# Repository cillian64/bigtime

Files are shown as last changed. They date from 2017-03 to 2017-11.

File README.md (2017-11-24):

# bigtime
A rather large wall clock using big 7-segment displays, powered by 802.3af
power-over-ethernet, and synchronised using NTP over wired ethernet.
Configuration is done using an interactive USB shell and stored in flash.

One of these clocks is deployed in each of Lecture Theatres 1 and 2 at the
[Department of Computer Science and Technology](https://www.cst.cam.ac.uk/)
(formerly known as the [Computer Lab](https://www.cl.cam.ac.uk/)), [University
of Cambridge](https://www.cam.ac.uk/), UK.

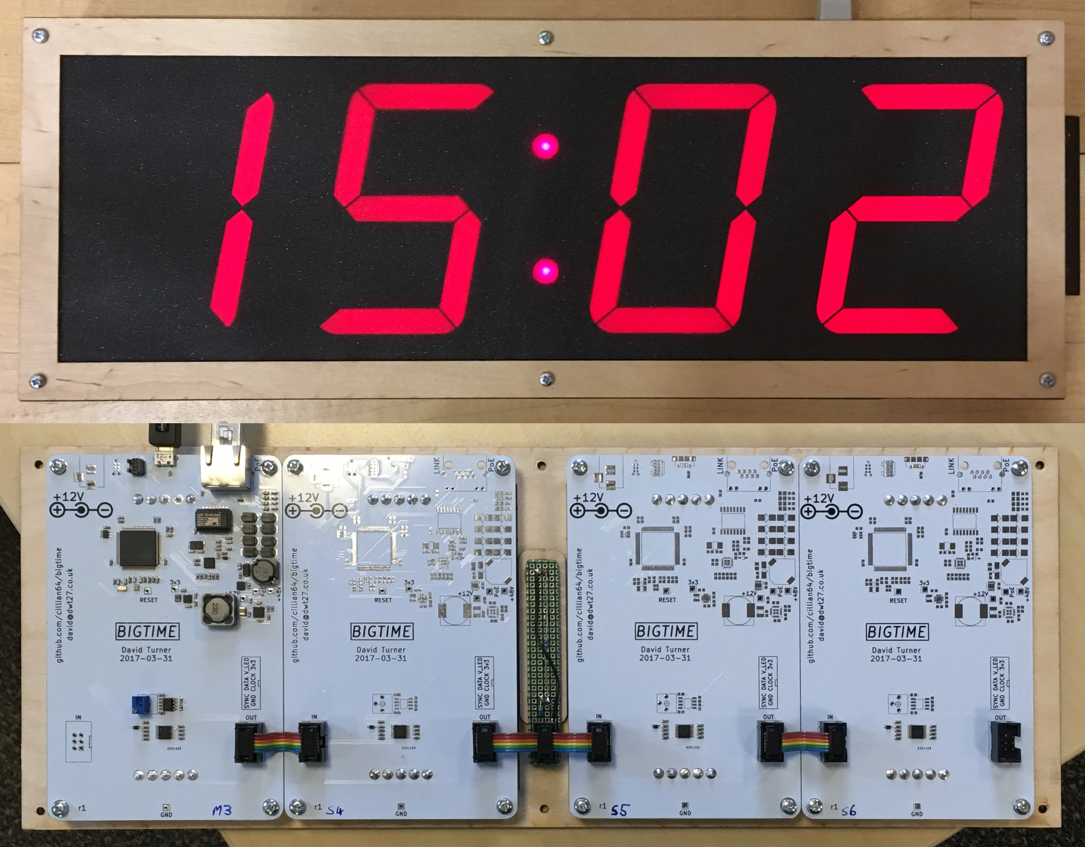
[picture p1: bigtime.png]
Photos of the front and back of the clock


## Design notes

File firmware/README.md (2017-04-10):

# Setting Up ChibiOS

```
git submodule update --init
cd ChibiOS/ext
7za x lwip-1.4.1_patched.7z
cd ..
patch -p0 < ../lwip_ip_addr.patch
git apply ../lwip_dhcp.patch
cd ..
```

# Logic
## Architecture
### Shared data
The STM32F4 RTC peripheral's date-time will hold the current time in UTC:
* Year (BCD)
* Month (BCD)
* Day of month (BCD)
* Day of week (BCD)
* Hour (BCD)
* Minute (BCD)
* Second (BCD)
* Sub-second

Other state is held in RAM:
* Time of last sync             (datetime)
* NTP server 1 status           (int)
* NTP server 1 query time       (datetime)
* NTP server 2 status           (int)
* NTP server 2 query time       (datetime)
* NTP server 3 status           (int)
* NTP server 3 query time       (datetime)

Non-volatile storage will be used to hold configuration:
* Network
    * DHCP enable               (bool)
    * IP address                (uint32_t IP address)
    * Network mask              (uint32_t IP address)
    * Gateway IP address        (uint32_t IP address)
    * DNS server 1              (uint32_t IP address)
    * DNS server 2              (uint32_t IP address)
* NTP
    * NTP server 1              (string)
    * NTP server 2              (string)
    * NTP server 3              (string)
    * Synchronisation interval  (uint16_t in minutes)
* Time and Display
    * Flashing second indicator (bool)
    * Display sync status       (bool)
    * Has seconds display       (bool)
    * Automatic BST adjustment  (bool)

### Threads
The display thread will retrieve the time from the RTC, the sync status from
the state structure, and the display settings from the configuration structure.
It will then drive the LED shift registers.  It will display the current time,
the seconds indicator if enabled, and the sync indicator if enabled and
currently unsynchronised.

The NTP thread will handle time synchronisation.  It will run through each NTP
server in the list and attempt to retrieve the time.  Upon a receive timeout it
will retry the same server several times.  Upon a network failure or KoD
response, it will proceed to the next server in the list.  If the final server
on the list fails, the NTP thread will return to the first server.  If all
servers are being avoided due to KoD, the NTP thread will wait until a server
becomes available again.  After a successful synchronisation it will update the
RTC peripheral and store the time of synchronisation.  It then waits until the
synchronisation interval has passed.

## Time anomalies
### Timezones
Only London time (GMT/BST) is supported currently.

### Daylight Savings adjustments
DST is applied using the rules for British Summer Time.  BST begins at 0100 UTC
on the last Sunday in March and ends at 0100 UTC on the last Sunday in October.
If the current date-time falls between these moments then the DST feature of
the RTC peripheral is enabled.  This automatically adds an hour to the time,
before timezone adjustment.

### Leap years
Knowing the calendar date, the RTC peripheral automatically compensates for
leap years.

### Leap seconds
If we pay no attention to leap seconds, we will be incorrect by 1 second
between a leap second and our next NTP synchronisation.  For a clock with a
precision of minutes, this seems acceptable.

NTP does provide advance warning of a leap second which we could use manually
adjust the RTC time between the leap second occurring and our next successful
synchronisation.  I strongly suspect the RTC peripheral will not handle a
seconds value of 60, so if we want to display the correct time, with a
precision of seconds, during the leap second, we will probably need to apply
the offset after reading the time from the RTC (i.e. at the same time as
timezone adjustment) and ensure our time-handling and display procedures can
handle a 61 second minute.

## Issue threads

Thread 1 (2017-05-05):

WAD connection needs diode

cillian64, 2017-05-05:
The barrel jack should connect directly to WAD on the MAX5969, then through a diode to the 12V bus.  This would prevent the 12V power from the MAX17503 triggering the WAD cutoff, causing the 48V and downstream buses to oscillate.

Workaround: The WAD track was cut

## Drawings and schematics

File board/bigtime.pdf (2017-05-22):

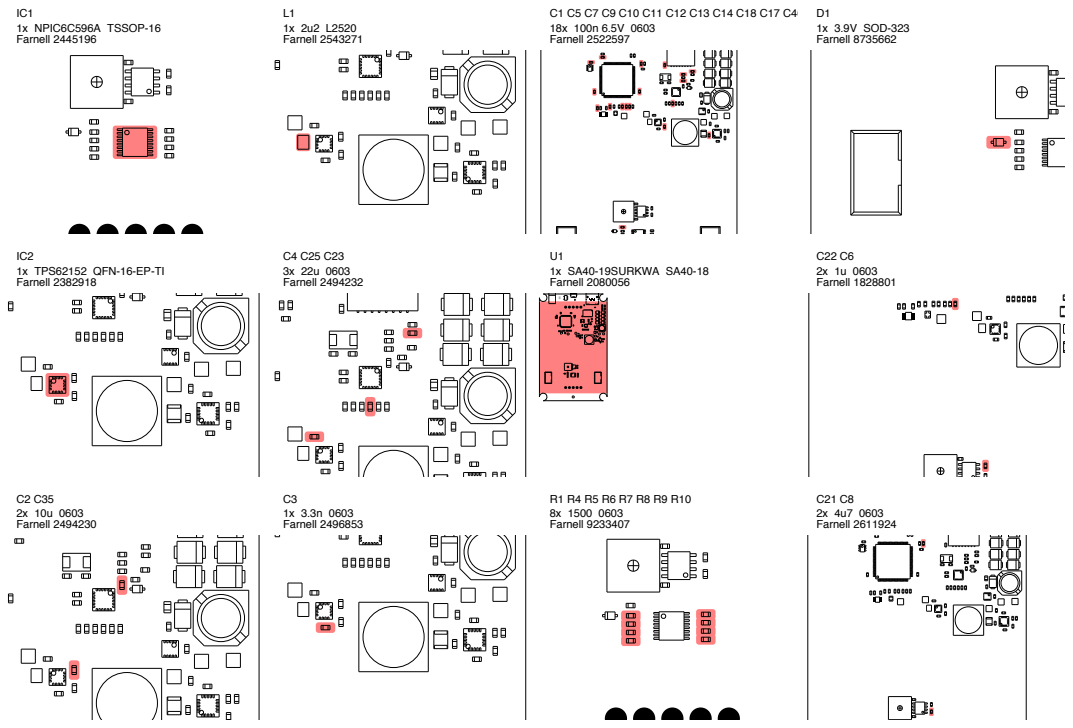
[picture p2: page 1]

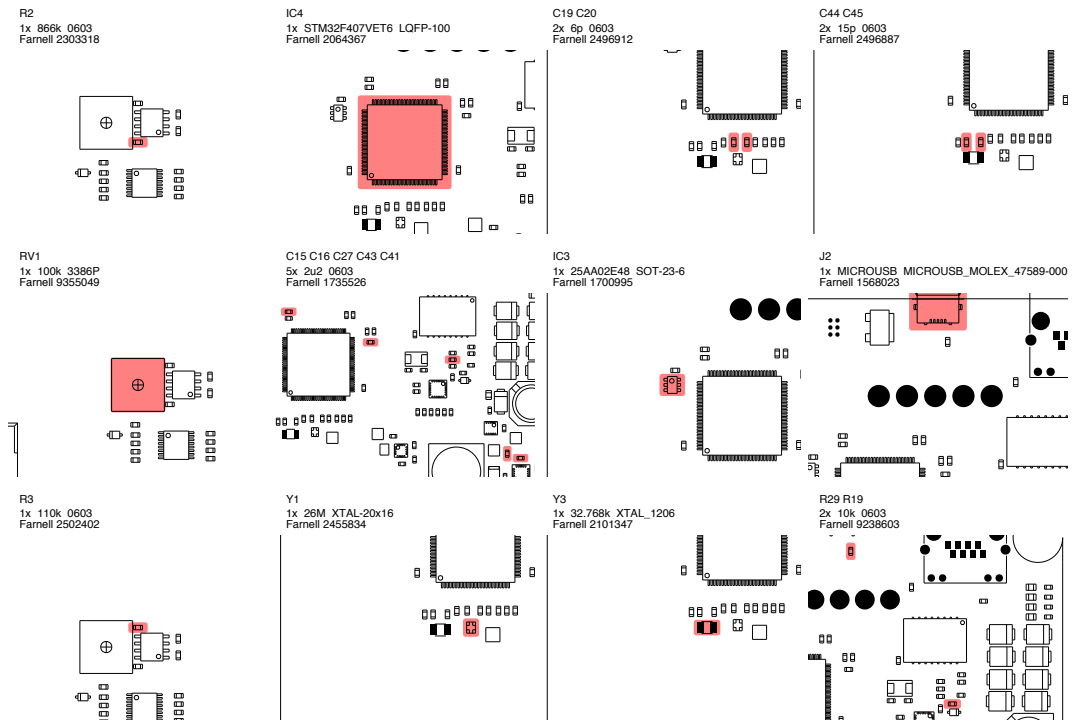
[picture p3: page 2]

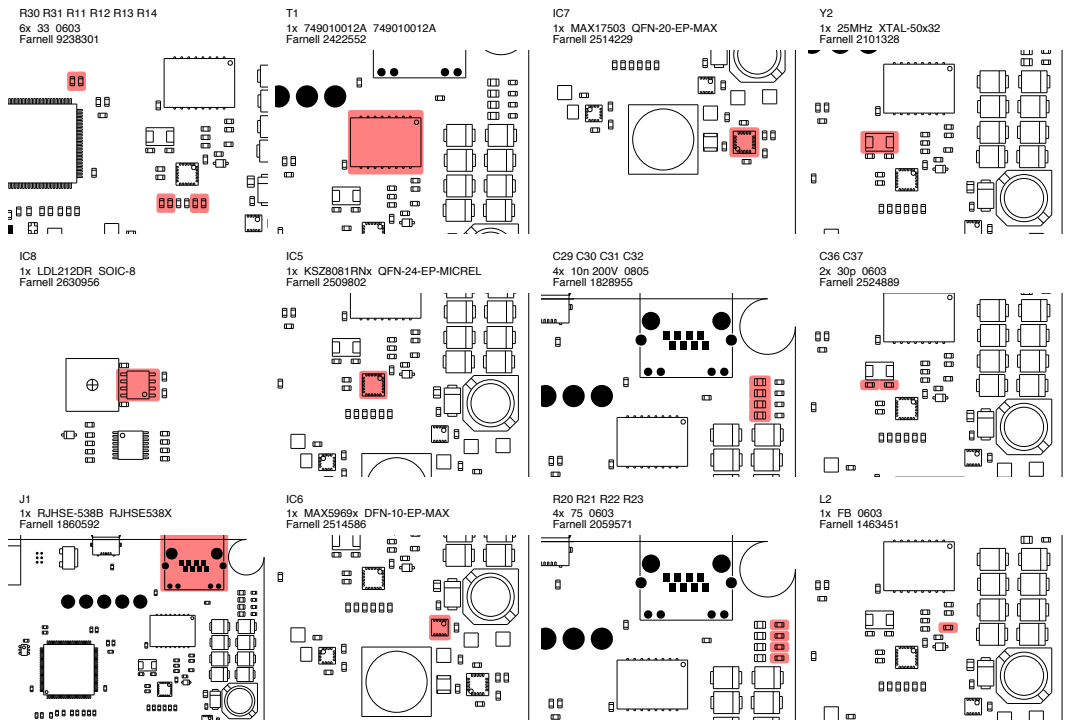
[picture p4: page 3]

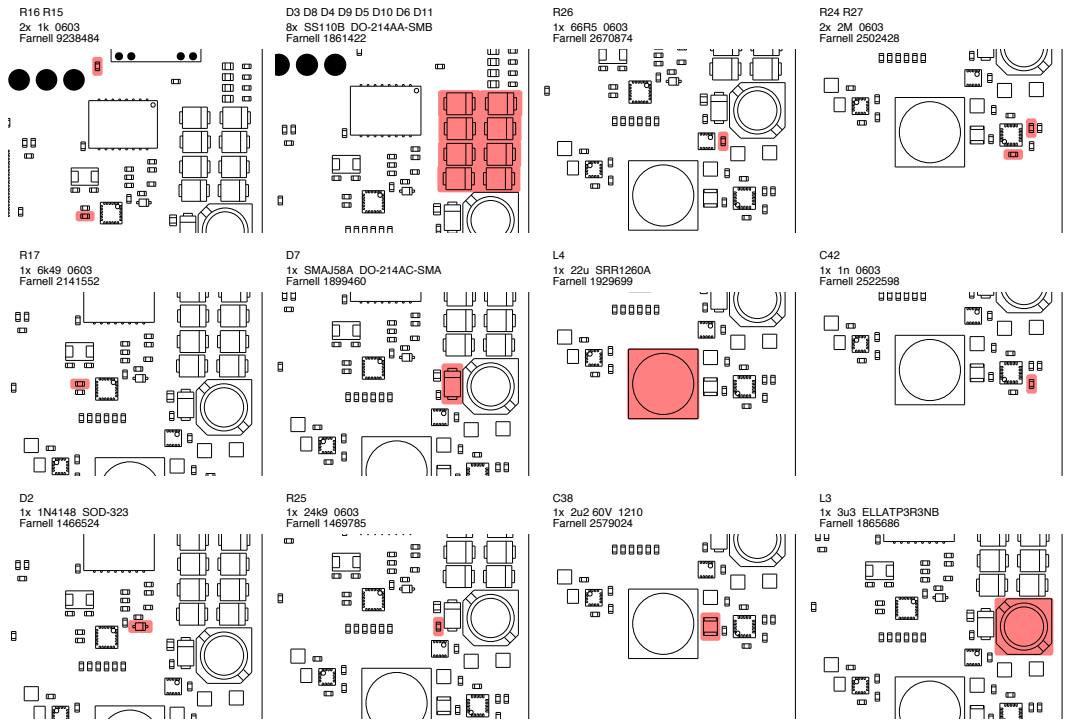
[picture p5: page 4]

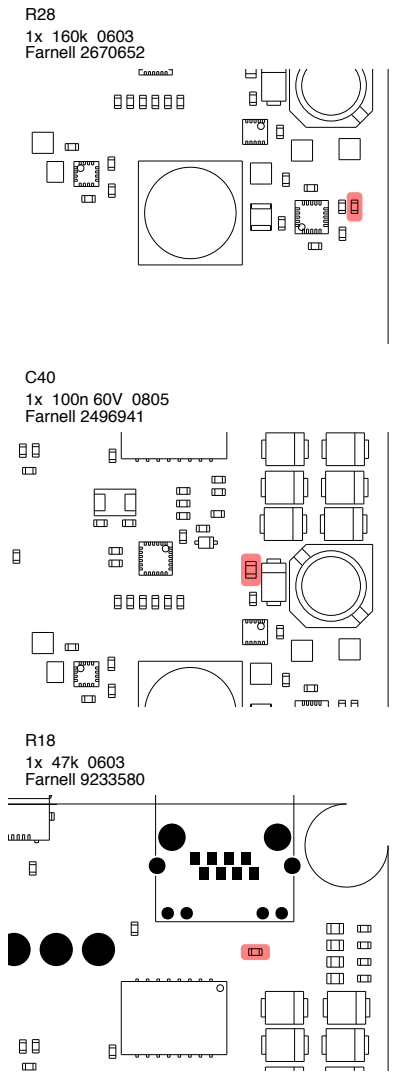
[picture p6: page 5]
1x 160k 0603 Farnell 2670652; C40 1x 100n 60V 0805 Farnell 2496941; R18 1x 47k 0603 Farnell 9233580

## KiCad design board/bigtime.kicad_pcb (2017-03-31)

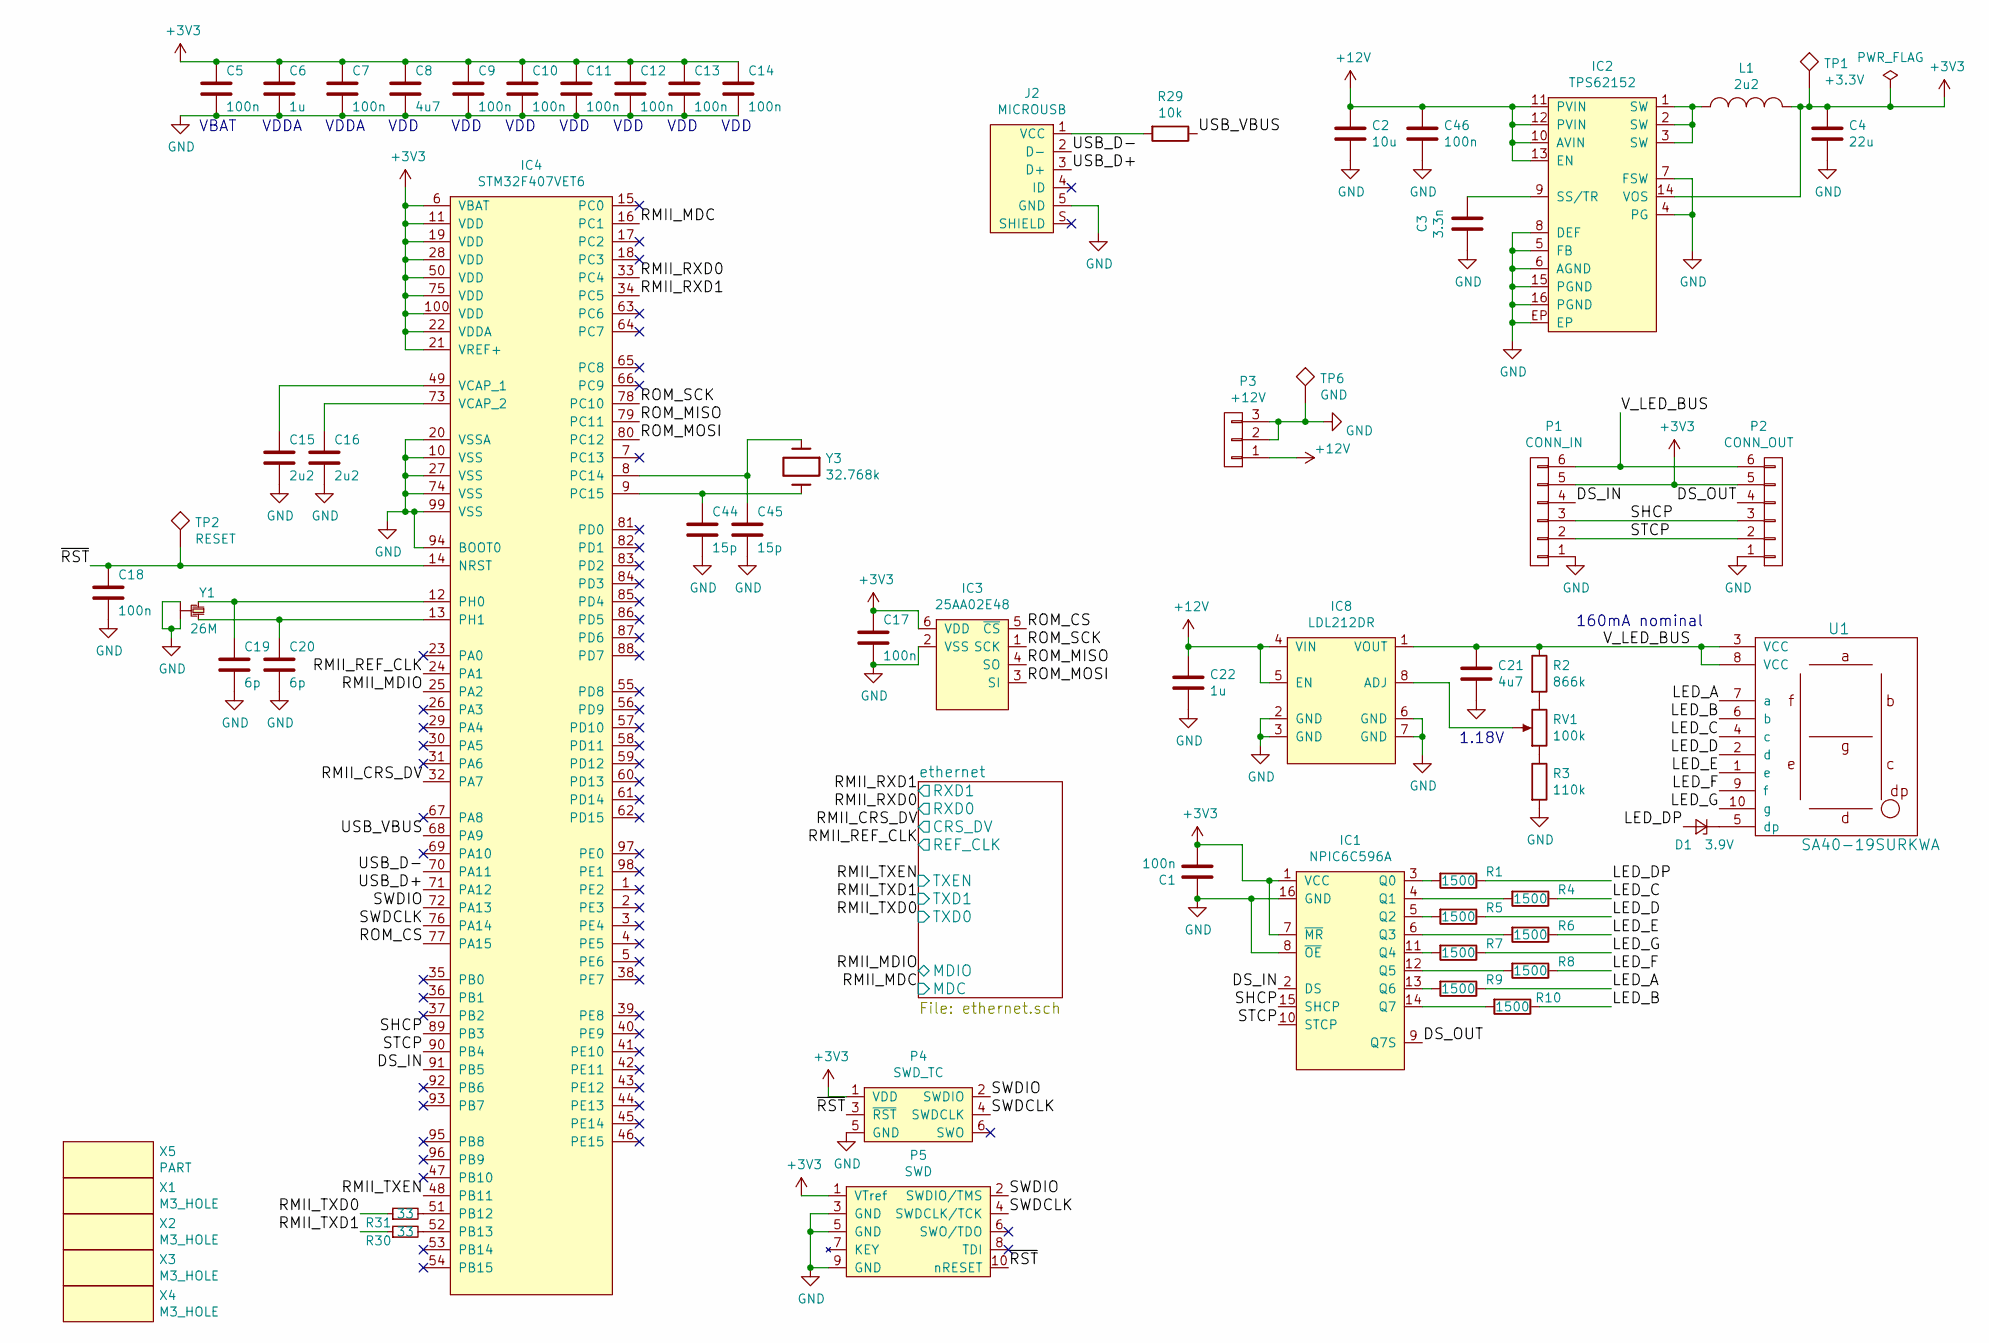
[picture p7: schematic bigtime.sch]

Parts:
C1, C5, C7, C9, C10, C11, C12, C13, C14, C17, C18, C46: 100n; 0603
C2: 10u; 0603; Farnell 2494230
C3: 3.3n; 0603; Farnell 2496853
C4: 22u; 0603; Farnell 2494232
C6, C22: 1u; 0603
C8, C21: 4u7; 0603
C15, C16: 2u2; 0603
C19, C20: 6p; 0603
C44, C45: 15p; 0603
D1: 3.9V; SOD-323; Farnell 8735662
IC1: NPIC6C596A; TSSOP-16; Farnell 2445196
IC2: TPS62152; QFN-16-EP-TI; Farnell 2382918
IC3: 25AA02E48; SOT-23-6; Farnell 1700995
IC4: STM32F407VET6; LQFP-100; Farnell 2064367
IC8: LDL212DR; SOIC-8; Farnell 2630956
J2: MICROUSB; MICROUSB_MOLEX_47589-0001; Farnell 1568023
L1: 2u2; L2520; Farnell 2543271
P1: CONN_IN; IDC_Header_Straight_6pins
P2: CONN_OUT; IDC_Header_Straight_6pins
P3: +12V; BARREL_JACK
P4: SWD_TC; TC2030-NL
P5: SWD; FTSH-105-01-F-D-K
R1, R4, R5, R6, R7, R8, R9, R10: 1500; 0603; Farnell 9233407
R2: 866k; 0603; Farnell 2303318
R3: 110k; 0603; Farnell 2502402
R29: 10k; 0603
R30, R31: 33; 0603
RV1: 100k; 3386P; Farnell 9355049
TP1: +3.3V; SIL-254P-01
TP2: RESET; SIL-254P-01
TP6: GND; SIL-254P-01
U1: SA40-19SURKWA; SA40-18; Farnell 2080056
X1, X2, X3, X4: M3_HOLE; M3_MOUNT
X5: PART; Polarity_Center_Positive_6mm_SilkScreen
Y1: 26M; XTAL-20x16; Farnell 2455834
Y3: 32.768k; XTAL_1206; Farnell 2101347

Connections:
+3V3: C1.2, C4.1, C5.1, C6.1, C7.1, C8.1, C9.1, C10.1, C11.1, C12.1, C13.1, C14.1, C17.1, IC1.1 (VCC), IC1.7 (~MR), IC2.14 (VOS), IC3.6 (VDD), IC4.6 (VBAT), IC4.11 (VDD), IC4.19 (VDD), IC4.21 (VREF+), IC4.22 (VDDA), IC4.28 (VDD), IC4.50 (VDD), IC4.75 (VDD), IC4.100 (VDD), L1.2, P1.5, P2.5, P4.1 (VDD), P5.1 (VTref), TP1.1; also elsewhere on the board
+12V: C2.1, C22.2, C46.1, IC2.10 (AVIN), IC2.11 (PVIN), IC2.12 (PVIN), IC2.13 (EN), IC8.4 (VIN), IC8.5 (EN), P3.1; also elsewhere on the board
/DS_IN: IC1.2 (DS), IC4.91 (PB5), P1.4
/DS_OUT: IC1.9 (Q7S), P2.4
/LED_A: R9.1, U1.7 (a)
/LED_B: R10.1, U1.6 (b)
/LED_C: R4.1, U1.4 (c)
/LED_D: R5.1, U1.2 (d)
/LED_DP: D1.2 (A), R1.1
/LED_E: R6.1, U1.1 (e)
/LED_F: R8.1, U1.9 (f)
/LED_G: R7.1, U1.10 (g)
/RMII_CRS_DV: IC4.32 (PA7); also elsewhere on the board
/RMII_MDC: IC4.16 (PC1); also elsewhere on the board
/RMII_MDIO: IC4.25 (PA2); also elsewhere on the board
/RMII_REF_CLK: IC4.24 (PA1); also elsewhere on the board
/RMII_RXD0: IC4.33 (PC4); also elsewhere on the board
/RMII_RXD1: IC4.34 (PC5); also elsewhere on the board
/RMII_TXD0: R31.1; also elsewhere on the board
/RMII_TXD1: R30.1; also elsewhere on the board
/RMII_TXEN: IC4.48 (PB11); also elsewhere on the board
/ROM_CS: IC3.5 (~CS), IC4.77 (PA15)
/ROM_MISO: IC3.4 (SO), IC4.79 (PC11)
/ROM_MOSI: IC3.3 (SI), IC4.80 (PC12)
/ROM_SCK: IC3.1 (SCK), IC4.78 (PC10)
/SHCP: IC1.15 (SHCP), IC4.89 (PB3), P1.3, P2.3
/STCP: IC1.10 (STCP), IC4.90 (PB4), P1.2, P2.2
/SWDCLK: IC4.76 (PA14), P4.4 (SWDCLK), P5.4 (SWDCLK/TCK)
/SWDIO: IC4.72 (PA13), P4.2 (SWDIO), P5.2 (SWDIO/TMS)
/USB_D+: IC4.71 (PA12), J2.3 (D+)
/USB_D-: IC4.70 (PA11), J2.2 (D-)
/USB_VBUS: IC4.68 (PA9), R29.1
/V_LED_BUS: C21.1, IC8.1 (VOUT), P1.6, P2.6, R2.1, U1.3 (VCC), U1.8 (VCC)
/~RST: C18.1, IC4.14 (NRST), P4.3 (~RST), P5.10 (nRESET), TP2.1
GND: C1.1, C2.2, C3.2, C4.2, C5.2, C6.2, C7.2, C8.2, C9.2, C10.2, C11.2, C12.2, C13.2, C14.2, C15.2, C16.2, C17.2, C18.2, C19.2, C20.2, C21.2, C22.1, C44.2, C45.2, C46.2, IC1.8 (~OE), IC1.16 (GND), IC2.4 (PG), IC2.5 (FB), IC2.6 (AGND), IC2.7 (FSW), IC2.8 (DEF), IC2.15 (PGND), IC2.16 (PGND), IC2.EP, IC3.2 (VSS), IC4.10 (VSS), IC4.20 (VSSA), IC4.27 (VSS), IC4.74 (VSS), IC4.94 (BOOT0), IC4.99 (VSS), IC8.2 (GND), IC8.3 (GND), IC8.6 (GND), IC8.7 (GND), J2.5 (GND), P1.1, P2.1, P3.2, P3.3, P4.5 (GND), P5.3 (GND), P5.5 (GND), P5.9 (GND), R3.2, TP6.1, Y1.2, Y1.4; also elsewhere on the board
unnamed: C3.1, IC2.9 (SS/TR)
unnamed: C15.1, IC4.49 (VCAP_1)
unnamed: C16.1, IC4.73 (VCAP_2)
unnamed: C19.1, IC4.12 (PH0), Y1.1
unnamed: C20.1, IC4.13 (PH1), Y1.3
unnamed: C44.1, IC4.9 (PC15), Y3.2
unnamed: C45.1, IC4.8 (PC14), Y3.1
unnamed: D1.1 (K), U1.5 (dp)
unnamed: IC1.3 (Q0), R1.2
unnamed: IC1.4 (Q1), R4.2
unnamed: IC1.5 (Q2), R5.2
unnamed: IC1.6 (Q3), R6.2
unnamed: IC1.11 (Q4), R7.2
unnamed: IC1.12 (Q5), R8.2
unnamed: IC1.13 (Q6), R9.2
unnamed: IC1.14 (Q7), R10.2
unnamed: IC2.1 (SW), IC2.2 (SW), IC2.3 (SW), L1.1
unnamed: IC4.51 (PB12), R31.2
unnamed: IC4.52 (PB13), R30.2
unnamed: IC8.8 (ADJ), RV1.2
unnamed: J2.1 (VCC), R29.2
unnamed: R2.2, RV1.3
unnamed: R3.1, RV1.1

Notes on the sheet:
160mA nominal
VBAT
VDDA
VDD
1.18V

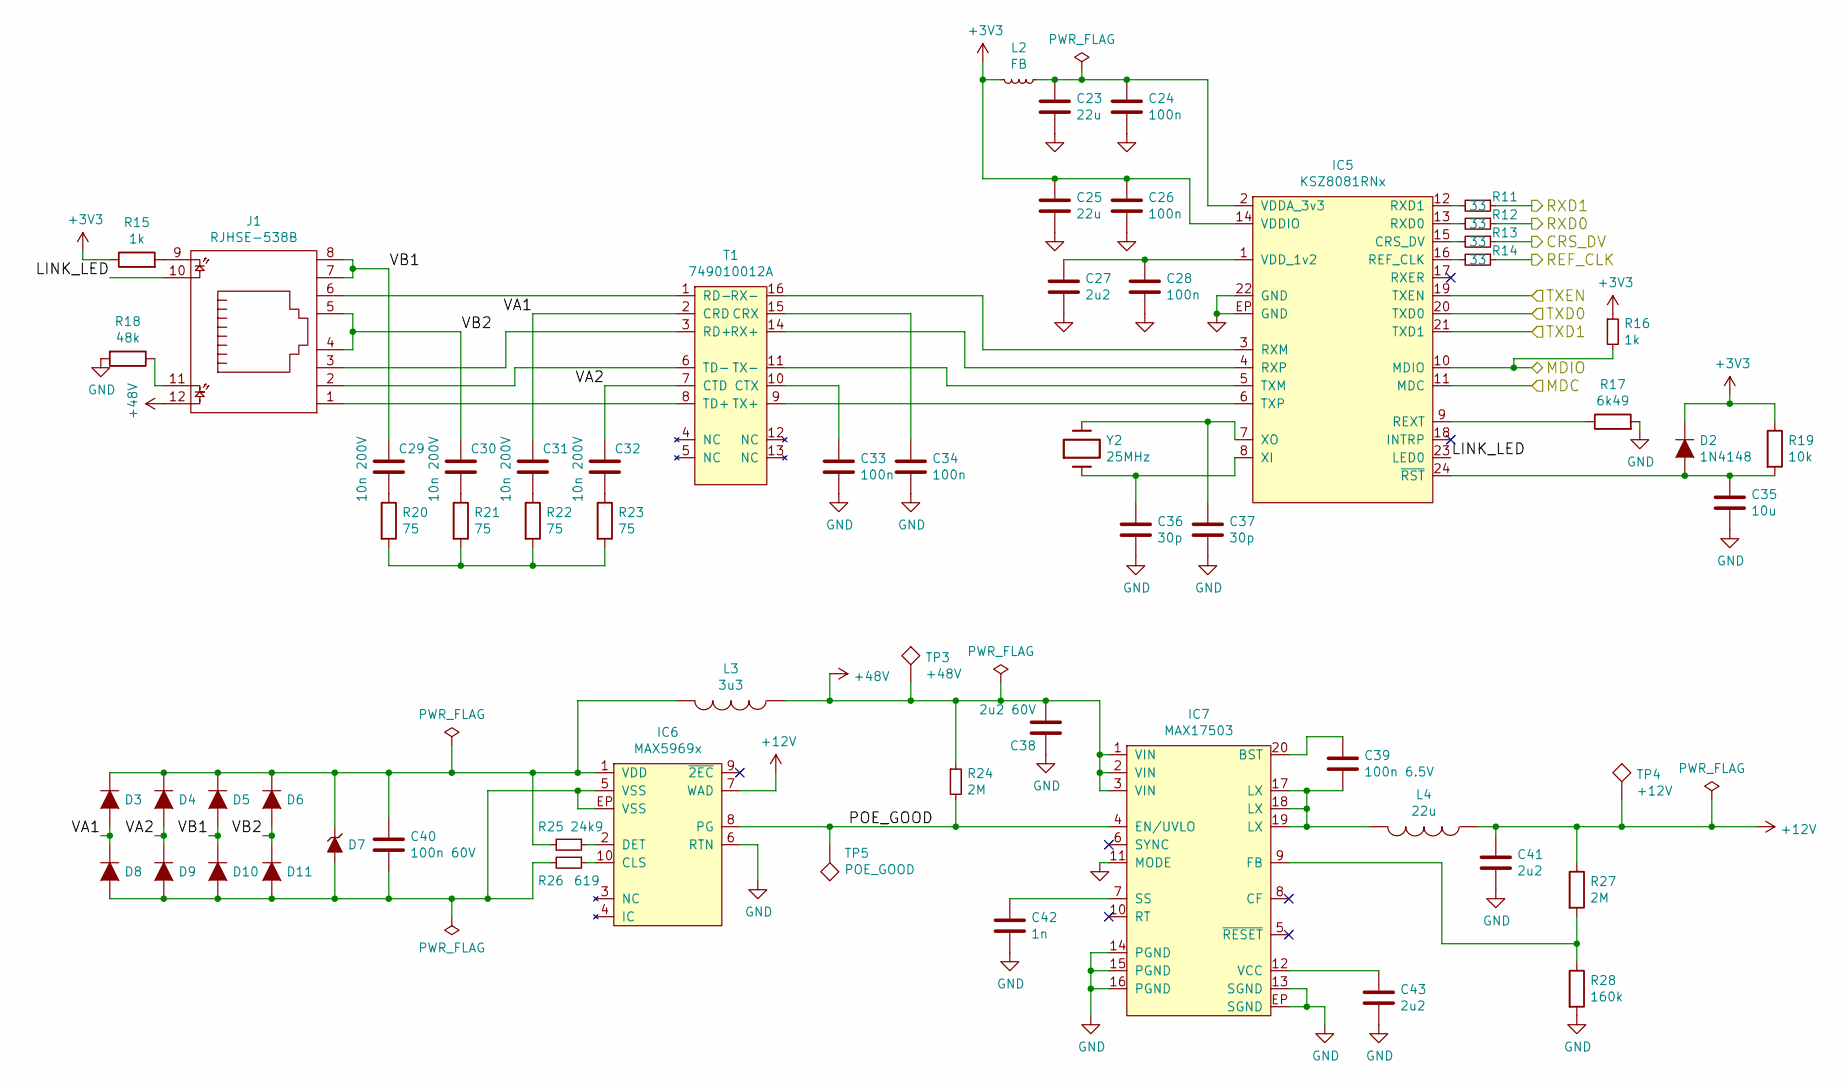
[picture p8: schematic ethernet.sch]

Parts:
C23, C25: 22u; 0603; Farnell 2494232
C24, C26, C28, C33, C34: 100n; 0603
C27: 2u2; 0603
C29, C30, C31, C32: 10n 200V; 0805; Farnell 1828955
C35: 10u; 0603
C36, C37: 30p; 0603
C38: 2u2 60V; 1210; Farnell 2579024
C39: 100n 6.5V; 0603
C40: 100n 60V; 0805; Farnell 2496941
C41, C43: 2u2; 0603; Farnell 1735526
C42: 1n; 0603
D2: 1N4148; SOD-323
D3, D4, D5, D6, D8, D9, D10, D11: SS110B; DO-214AA-SMB
D7: SMAJ58A; DO-214AC-SMA
IC5: KSZ8081RNx; QFN-24-EP-MICREL; Farnell 2509802
IC6: MAX5969x; DFN-10-EP-MAX; Farnell 2514586
IC7: MAX17503; QFN-20-EP-MAX; Farnell 2514229
J1: RJHSE-538B; RJHSE538X; Farnell 1860592
L2: FB; 0603
L3: 3u3; ELLATP3R3NB; Farnell 1865686
L4: 22u; SRR1260A; Farnell 1929699
R11, R12, R13, R14: 33; 0603
R15, R16: 1k; 0603
R17: 6k49; 0603
R18: 48k; 0603
R19: 10k; 0603
R20, R21, R22, R23: 75; 0603
R24, R27: 2M; 0603; Farnell 2502428
R25: 24k9; 0603
R26: 619; 0603
R28: 160k; 0603; Farnell 2670652
T1: 749010012A; Farnell 2422552
TP3: +48V; SIL-254P-01
TP4: +12V; SIL-254P-01
TP5: POE_GOOD; SIL-254P-01
Y2: 25MHz; XTAL-50x32

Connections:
+3V3: C25.1, C26.1, D2.1 (K), IC5.14 (VDDIO), L2.2, R15.1, R16.1, R19.1; also elsewhere on the board
+12V: C41.1, IC6.7 (WAD), L4.1, R27.1, TP4.1; also elsewhere on the board
+48V: C38.2, IC7.1 (VIN), IC7.2 (VIN), IC7.3 (VIN), J1.12, L3.1, R24.1, TP3.1
/RMII_CRS_DV: R13.1; also elsewhere on the board
/RMII_MDC: IC5.11 (MDC); also elsewhere on the board
/RMII_MDIO: IC5.10 (MDIO), R16.2; also elsewhere on the board
/RMII_REF_CLK: R14.1; also elsewhere on the board
/RMII_RXD0: R12.1; also elsewhere on the board
/RMII_RXD1: R11.1; also elsewhere on the board
/RMII_TXD0: IC5.20 (TXD0); also elsewhere on the board
/RMII_TXD1: IC5.21 (TXD1); also elsewhere on the board
/RMII_TXEN: IC5.19 (TXEN); also elsewhere on the board
/ethernet/LINK_LED: IC5.23 (LED0), J1.10
/ethernet/POE_GOOD: IC6.8 (PG), IC7.4 (EN/UVLO), R24.2, TP5.1
/ethernet/VA1: C31.1, D3.2 (A), D8.1 (K), T1.2 (CRD)
/ethernet/VA2: C32.1, D4.2 (A), D9.1 (K), T1.7 (CTD)
/ethernet/VB1: C29.1, D5.2 (A), D10.1 (K), J1.7, J1.8
/ethernet/VB2: C30.1, D6.2 (A), D11.1 (K), J1.4, J1.5
GND: C23.2, C24.2, C25.2, C26.2, C27.2, C28.2, C33.2, C34.2, C35.2, C36.2, C37.2, C38.1, C41.2, C42.2, C43.2, IC5.22 (GND), IC5.EP (GND), IC6.6 (RTN), IC7.11 (MODE), IC7.13 (SGND), IC7.14 (PGND), IC7.15 (PGND), IC7.16 (PGND), IC7.EP (SGND), R17.2, R18.2, R28.2; also elsewhere on the board
unnamed: C23.1, C24.1, IC5.2 (VDDA_3v3), L2.1
unnamed: C27.1, C28.1, IC5.1 (VDD_1v2)
unnamed: C29.2, R20.1
unnamed: C30.2, R21.1
unnamed: C31.2, R22.1
unnamed: C32.2, R23.1
unnamed: C33.1, T1.10 (CTX)
unnamed: C34.1, T1.15 (CRX)
unnamed: C35.1, D2.2 (A), IC5.24 (~RST), R19.2
unnamed: C36.1, IC5.8 (XI), Y2.1
unnamed: C37.1, IC5.7 (XO), Y2.2
unnamed: C39.1, IC7.20 (BST)
unnamed: C39.2, IC7.17 (LX), IC7.18 (LX), IC7.19 (LX), L4.2
unnamed: C40.1, D3.1 (K), D4.1 (K), D5.1 (K), D6.1 (K), D7.1 (K), IC6.1 (VDD), L3.2, R25.2
unnamed: C40.2, D7.2 (A), D8.2 (A), D9.2 (A), D10.2 (A), D11.2 (A), IC6.5 (VSS), IC6.EP (VSS), R26.2
unnamed: C42.1, IC7.7 (SS)
unnamed: C43.1, IC7.12 (VCC)
unnamed: IC5.3 (RXM), T1.16 (RX-)
unnamed: IC5.4 (RXP), T1.14 (RX+)
unnamed: IC5.5 (TXM), T1.11 (TX-)
unnamed: IC5.6 (TXP), T1.9 (TX+)
unnamed: IC5.9 (REXT), R17.1
unnamed: IC5.12 (RXD1), R11.2
unnamed: IC5.13 (RXD0), R12.2
unnamed: IC5.15 (CRS_DV), R13.2
unnamed: IC5.16 (REF_CLK), R14.2
unnamed: IC6.2 (DET), R25.1
unnamed: IC6.10 (CLS), R26.1
unnamed: IC7.9 (FB), R27.2, R28.1
unnamed: J1.1, T1.8 (TD+)
unnamed: J1.2, T1.6 (TD-)
unnamed: J1.3, T1.3 (RD+)
unnamed: J1.6, T1.1 (RD-)
unnamed: J1.9, R15.2
unnamed: J1.11, R18.1
unnamed: R20.2, R21.2, R22.2, R23.2

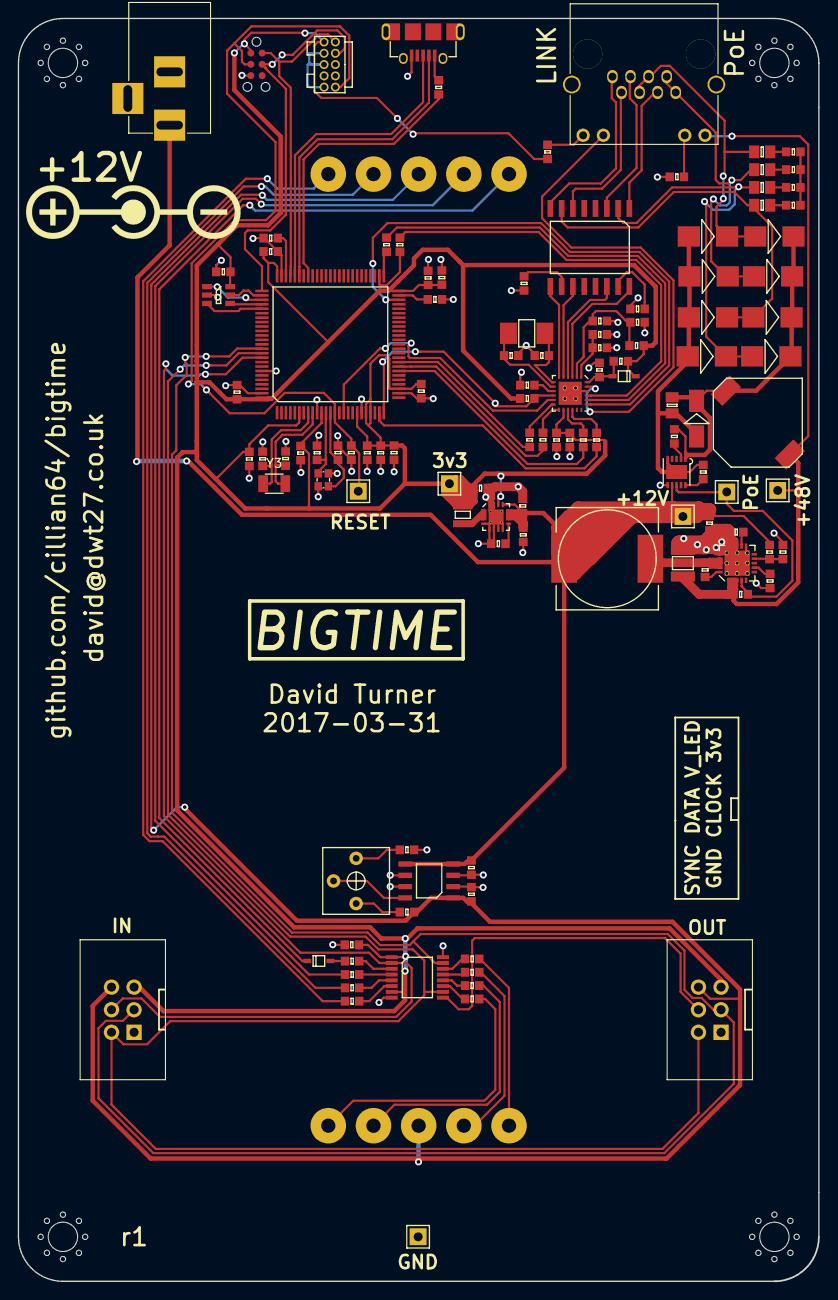
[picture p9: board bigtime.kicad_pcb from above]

Board: 2 copper layers, 90.0 x 142.0 mm, 124 parts (1 on the bottom side), 101 nets.

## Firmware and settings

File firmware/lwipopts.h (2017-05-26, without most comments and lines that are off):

#define __LWIPOPT_H__
#define LWIP_TIMEVAL_PRIVATE 0
#define SYS_LIGHTWEIGHT_PROT            0
#define NO_SYS                          0
#define NO_SYS_NO_TIMERS                0
#define MEMCPY(dst,src,len)             memcpy(dst,src,len)
#define SMEMCPY(dst,src,len)            memcpy(dst,src,len)
#define MEM_LIBC_MALLOC                 0
#define MEMP_MEM_MALLOC                 0
#define MEM_ALIGNMENT                   4
#define MEM_SIZE                        1600
#define MEMP_SEPARATE_POOLS             0
#define MEMP_OVERFLOW_CHECK             1
#define MEMP_SANITY_CHECK               1
#define MEM_USE_POOLS                   0
#define MEM_USE_POOLS_TRY_BIGGER_POOL   0
#define MEMP_USE_CUSTOM_POOLS           0
#define LWIP_ALLOW_MEM_FREE_FROM_OTHER_CONTEXT 0
#define MEMP_NUM_PBUF                   16
#define MEMP_NUM_RAW_PCB                4
#define MEMP_NUM_UDP_PCB                4
#define MEMP_NUM_TCP_PCB                5
#define MEMP_NUM_TCP_PCB_LISTEN         8
#define MEMP_NUM_TCP_SEG                16
#define MEMP_NUM_REASSDATA              5
#define MEMP_NUM_FRAG_PBUF              15
#define MEMP_NUM_ARP_QUEUE              30
#define MEMP_NUM_IGMP_GROUP             8
#define MEMP_NUM_SYS_TIMEOUT            (LWIP_TCP + IP_REASSEMBLY + LWIP_ARP + (2*LWIP_DHCP) + LWIP_AUTOIP + LWIP_IGMP + LWIP_DNS + PPP_SUPPORT)
#define MEMP_NUM_NETBUF                 2
#define MEMP_NUM_NETCONN                4
#define MEMP_NUM_TCPIP_MSG_API          8
#define MEMP_NUM_TCPIP_MSG_INPKT        8
#define MEMP_NUM_SNMP_NODE              50
#define MEMP_NUM_SNMP_ROOTNODE          30
#define MEMP_NUM_SNMP_VARBIND           2
#define MEMP_NUM_SNMP_VALUE             3
#define MEMP_NUM_NETDB                  1
#define MEMP_NUM_LOCALHOSTLIST          1
#define MEMP_NUM_PPPOE_INTERFACES       1
#define PBUF_POOL_SIZE                  16
#define LWIP_ARP                        1
#define ARP_TABLE_SIZE                  10
#define ARP_QUEUEING                    0
#define ETHARP_TRUST_IP_MAC             0
#define ETHARP_SUPPORT_VLAN             0
#define LWIP_ETHERNET                   (LWIP_ARP || PPPOE_SUPPORT)
#define ETH_PAD_SIZE                    0
#define ETHARP_SUPPORT_STATIC_ENTRIES   0
#define IP_FORWARD                      0
#define IP_OPTIONS_ALLOWED              1
#define IP_REASSEMBLY                   1
#define IP_FRAG                         1
#define IP_REASS_MAXAGE                 3
#define IP_REASS_MAX_PBUFS              10
#define IP_FRAG_USES_STATIC_BUF         0
#if IP_FRAG_USES_STATIC_BUF && !defined(IP_FRAG_MAX_MTU)
#define IP_FRAG_MAX_MTU                 1500
#endif
#define IP_DEFAULT_TTL                  255
#define IP_SOF_BROADCAST                0
#define IP_SOF_BROADCAST_RECV           0
#define IP_FORWARD_ALLOW_TX_ON_RX_NETIF 0
#define LWIP_RANDOMIZE_INITIAL_LOCAL_PORTS 0
#define LWIP_ICMP                       1
#define ICMP_TTL                       (IP_DEFAULT_TTL)
#define LWIP_BROADCAST_PING             1
#define LWIP_MULTICAST_PING             0
#define LWIP_RAW                        1
#define RAW_TTL                        (IP_DEFAULT_TTL)
#define LWIP_DHCP                       1
#define LWIP_DHCP_BOOTP_FILE            0
#define DHCP_DOES_ARP_CHECK             ((LWIP_DHCP) && (LWIP_ARP))
#define LWIP_AUTOIP                     0
#define LWIP_DHCP_AUTOIP_COOP           0
#define LWIP_DHCP_AUTOIP_COOP_TRIES     9
#define LWIP_SNMP                       0
#define SNMP_CONCURRENT_REQUESTS        1
#define SNMP_TRAP_DESTINATIONS          1
#define SNMP_PRIVATE_MIB                0
#define SNMP_SAFE_REQUESTS              1
#define SNMP_MAX_OCTET_STRING_LEN       127
#define SNMP_MAX_TREE_DEPTH             15
#define SNMP_MAX_VALUE_SIZE             LWIP_MAX((SNMP_MAX_OCTET_STRING_LEN)+1, sizeof(s32_t)*(SNMP_MAX_TREE_DEPTH))
#define LWIP_IGMP                       0
#define LWIP_DNS                        1
#define DNS_TABLE_SIZE                  1
#define DNS_MAX_NAME_LENGTH             256
#define DNS_MAX_SERVERS                 2
#define DNS_DOES_NAME_CHECK             1
#define DNS_MSG_SIZE                    512
#define DNS_LOCAL_HOSTLIST              0
#define DNS_LOCAL_HOSTLIST_IS_DYNAMIC   0
#define LWIP_UDP                        1
#define LWIP_UDPLITE                    0
#define UDP_TTL                         (IP_DEFAULT_TTL)
#define LWIP_NETBUF_RECVINFO            0
#define LWIP_TCP                        0
#define TCP_TTL                         (IP_DEFAULT_TTL)
#define TCP_WND                         (4 * TCP_MSS)
#define TCP_MAXRTX                      12
#define TCP_SYNMAXRTX                   6
#define TCP_QUEUE_OOSEQ                 (LWIP_TCP)
#define TCP_MSS                         536
#define TCP_CALCULATE_EFF_SEND_MSS      1
#define TCP_SND_BUF                     (2 * TCP_MSS)
#define TCP_SND_QUEUELEN                ((4 * (TCP_SND_BUF) + (TCP_MSS - 1))/(TCP_MSS))
#define TCP_SNDLOWAT                    LWIP_MIN(LWIP_MAX(((TCP_SND_BUF)/2), (2 * TCP_MSS) + 1), (TCP_SND_BUF) - 1)
#define TCP_SNDQUEUELOWAT               LWIP_MAX(((TCP_SND_QUEUELEN)/2), 5)
#define TCP_OOSEQ_MAX_BYTES             0
#define TCP_OOSEQ_MAX_PBUFS             0
#define TCP_LISTEN_BACKLOG              0
#define TCP_DEFAULT_LISTEN_BACKLOG      0xff
#define TCP_OVERSIZE                    TCP_MSS
#define LWIP_TCP_TIMESTAMPS             0
#define TCP_WND_UPDATE_THRESHOLD   (TCP_WND / 4)
#if !defined(LWIP_EVENT_API) && !defined(LWIP_CALLBACK_API)
#define LWIP_EVENT_API                  0
#define LWIP_CALLBACK_API               1
#endif
#define PBUF_LINK_HLEN                  (14 + ETH_PAD_SIZE)
#define PBUF_POOL_BUFSIZE               LWIP_MEM_ALIGN_SIZE(TCP_MSS+40+PBUF_LINK_HLEN)
#define LWIP_NETIF_HOSTNAME             1
#define LWIP_NETIF_API                  0
#define LWIP_NETIF_STATUS_CALLBACK      0
#define LWIP_NETIF_LINK_CALLBACK        0
#define LWIP_NETIF_REMOVE_CALLBACK      0
#define LWIP_NETIF_HWADDRHINT           0
#define LWIP_NETIF_LOOPBACK             0
#define LWIP_LOOPBACK_MAX_PBUFS         0
#define LWIP_NETIF_LOOPBACK_MULTITHREADING    (!NO_SYS)
#define LWIP_NETIF_TX_SINGLE_PBUF             0
#define LWIP_HAVE_LOOPIF                0
#define LWIP_HAVE_SLIPIF                0
#define TCPIP_THREAD_NAME              "tcpip_thread"
#define TCPIP_THREAD_STACKSIZE          1024
#define TCPIP_THREAD_PRIO               (LOWPRIO + 1)
#define TCPIP_MBOX_SIZE                 MEMP_NUM_PBUF
#define SLIPIF_THREAD_NAME             "slipif_loop"
#define SLIPIF_THREAD_STACKSIZE         1024
#define SLIPIF_THREAD_PRIO              (LOWPRIO + 1)
#define PPP_THREAD_NAME                "pppInputThread"
#define PPP_THREAD_STACKSIZE            1024
#define PPP_THREAD_PRIO                 (LOWPRIO + 1)
#define DEFAULT_THREAD_NAME            "lwIP"
#define DEFAULT_THREAD_STACKSIZE        1024
#define DEFAULT_THREAD_PRIO             (LOWPRIO + 1)
#define DEFAULT_RAW_RECVMBOX_SIZE       4
#define DEFAULT_UDP_RECVMBOX_SIZE       4
#define DEFAULT_TCP_RECVMBOX_SIZE       40
#define DEFAULT_ACCEPTMBOX_SIZE         4
#define LWIP_TCPIP_CORE_LOCKING         0
#define LWIP_TCPIP_CORE_LOCKING_INPUT   0
#define LWIP_NETCONN                    1
#define LWIP_TCPIP_TIMEOUT              1
#define LWIP_SOCKET                     1
#define LWIP_COMPAT_SOCKETS             1
#define LWIP_POSIX_SOCKETS_IO_NAMES     1
#define LWIP_TCP_KEEPALIVE              0
#define LWIP_SO_SNDTIMEO                0
#define LWIP_SO_RCVTIMEO                0
#define LWIP_SO_RCVBUF                  0
#define RECV_BUFSIZE_DEFAULT            INT_MAX
#define SO_REUSE                        0
#define SO_REUSE_RXTOALL                0
#define LWIP_STATS                      1
#if LWIP_STATS
#define LWIP_STATS_DISPLAY              0
#define LINK_STATS                      1
#define ETHARP_STATS                    (LWIP_ARP)
#define IP_STATS                        1
#define IPFRAG_STATS                    (IP_REASSEMBLY || IP_FRAG)
#define ICMP_STATS                      1
#define IGMP_STATS                      (LWIP_IGMP)
#define UDP_STATS                       (LWIP_UDP)
#define TCP_STATS                       (LWIP_TCP)
#define MEM_STATS                       ((MEM_LIBC_MALLOC == 0) && (MEM_USE_POOLS == 0))
#define MEMP_STATS                      (MEMP_MEM_MALLOC == 0)
#define SYS_STATS                       (NO_SYS == 0)
#else
#define LINK_STATS                      0
#define IP_STATS                        0
#define IPFRAG_STATS                    0
#define ICMP_STATS                      0
#define IGMP_STATS                      0
#define UDP_STATS                       0
#define TCP_STATS                       0
#define MEM_STATS                       0
#define MEMP_STATS                      0
#define SYS_STATS                       0
#define LWIP_STATS_DISPLAY              0
#endif
#define PPP_SUPPORT                     0
#define PPPOE_SUPPORT                   0
#define PPPOS_SUPPORT                   PPP_SUPPORT
#if PPP_SUPPORT
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

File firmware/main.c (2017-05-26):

#include <string.h>

#include "ch.h"
#include "hal.h"

#include "chprintf.h"
#include "shell.h"

#include "lwipthread.h"

#include "lwip/opt.h"
#include "lwip/arch.h"
#include "lwip/api.h"
#include "lwip/dns.h"
#include "lwip/netif.h"

#include "rom.h"
#include "rtc.h"
#include "display.h"
#include "sntp.h"
#include "config.h"
#include "usbshell.h"

static THD_WORKING_AREA(waUsbSer, 0x100);
static THD_WORKING_AREA(waDisplay, 0x100);

/* On hard fault, copy HARDFAULT_PSP to the sp reg so gdb can give a trace */
void **HARDFAULT_PSP;
register void *stack_pointer asm("sp");
void HardFault_Handler(void) {
    asm("mrs %0, psp" : "=r"(HARDFAULT_PSP) : :);
    stack_pointer = HARDFAULT_PSP;
    while(1);
}

int main(void) {
    uint8_t mac_addr[6];
    struct ip_addr address, netmask, gateway;
    IP4_ADDR(&address, 0, 0, 0, 0);
    IP4_ADDR(&netmask, 255, 255, 255, 255);
    IP4_ADDR(&gateway, 0, 0, 0, 0);
    lwipthread_opts_t lwipopts = {
        .macaddress = mac_addr,
        .address = address.addr,
        .netmask = netmask.addr,
        .gateway = gateway.addr,
    };

    /* Initialise ChibiOS */
    halInit();
    chSysInit();

    // Blank the display:
    display_init();

    /* Read our MAC address from the EEPROM */
    rom_get_eui48(mac_addr);

    // Load config from flash
    config_load();

    // If not using DHCP, set details from config:
    if(!bigtime_config.net_dhcp_enable)
    {
        lwipopts.address = bigtime_config.net_static_ip.addr;
        lwipopts.netmask = bigtime_config.net_static_netmask.addr;
        lwipopts.gateway = bigtime_config.net_static_gateway.addr;
        dns_setserver(0, &bigtime_config.net_static_dns1);
        dns_setserver(1, &bigtime_config.net_static_dns2);
    }

    /* Initialise lwIP (automatically does DHCP if ip == 0.0.0.0) */
    lwipInit(&lwipopts);
    netif_set_hostname(netif_default, bigtime_config.net_hostname);

    // Initialise the state structure
    memset(&bigtime_state, 0, sizeof(bigtime_state));

    // Force sync on boot:
    bigtime_state.force_sync = true;

    // Start USB config shell and display thread
    chThdCreateStatic(waUsbSer, sizeof(waUsbSer), NORMALPRIO, UsbSerThread,
            NULL);
    chThdCreateStatic(waDisplay, sizeof(waDisplay), NORMALPRIO, DisplayThread,
            NULL);


    uint64_t ntpDateTime;
    RTCDateTime rtcDateTime;
    while(true)
    {
        bigtime_state.syncing = true;

        // Poll the NTP servers until we successfully sync.
        while(true)
        {
            if(get_ntp_timestamp(bigtime_config.ntp_server1, &ntpDateTime)
                    == SNTP_SUCCESS)
                break;

            if(get_ntp_timestamp(bigtime_config.ntp_server2, &ntpDateTime)
                    == SNTP_SUCCESS)
                break;

            if(get_ntp_timestamp(bigtime_config.ntp_server3, &ntpDateTime)
                    == SNTP_SUCCESS)
                break;

            // If none of the servers respond, wait for a period before trying
            // again.  On cold boot or force sync, wait 5s, otherwise wait 5
            // minutes
            if(bigtime_state.force_sync)
                chThdSleepMilliseconds(5 * 1000);
            else
                for(int i=0; i<5*60; i++)
                    if(bigtime_state.force_sync)
                        break;
                    else
                        chThdSleepMilliseconds(1000);
        }

        // Set the RTC from the NTP response.
        rtc_from_ntp(&rtcDateTime, ntpDateTime);
        rtc_set(&rtcDateTime);
        bigtime_state.syncing = false;

        // Set time last synced to rtcDateTime
        bigtime_state.last_synced = rtcDateTime;

        // And reset the force_sync flag.
        bigtime_state.force_sync = false;

        // Pause here otherwise we accidentally sync several times
        chThdSleepMilliseconds(3000);

        // And wait until it's time for our next sync
        while(true)
        {
            rtcGetTime(&RTCD1, &rtcDateTime);
            if(bigtime_state.force_sync)
                break;

            // Millisecond-of-day of sync time:
            uint32_t sync_millisecond = 0;
            sync_millisecond += bigtime_config.ntp_sync_time / 100 * 3600000u;
            sync_millisecond += (bigtime_config.ntp_sync_time % 100) * 60000u;

            // If last sync was on a different day to today:
            if((bigtime_state.last_synced.year != rtcDateTime.year) ||
               (bigtime_state.last_synced.month != rtcDateTime.month) ||
               (bigtime_state.last_synced.day != rtcDateTime.day))
            {
                // If time-of-day is after the sync time:
                if(rtcDateTime.millisecond > sync_millisecond)
                    break;  // Sync
            }
            else
                // Last sync was today.
                if(bigtime_state.last_synced.millisecond <= sync_millisecond
                    && rtcDateTime.millisecond > sync_millisecond)
                    break;  // Sync

            chThdSleepMilliseconds(1000);
        }
    }
}

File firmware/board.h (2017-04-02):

/*
    ChibiOS - Copyright (C) 2006..2016 Giovanni Di Sirio
    Licensed under the Apache License, Version 2.0 (the "License");
    you may not use this file except in compliance with the License.
    You may obtain a copy of the License at
    http://www.apache.org/licenses/LICENSE-2.0
    Unless required by applicable law or agreed to in writing, software
    distributed under the License is distributed on an "AS IS" BASIS,
    WITHOUT WARRANTIES OR CONDITIONS OF ANY KIND, either express or implied.
    See the License for the specific language governing permissions and
    limitations under the License.
*/

/*
    Generated by gen-board.h.py based on ../bigtime/firmware/board.yaml
*/

#ifndef _BOARD_H_
#define _BOARD_H_


/*
    Setup for Bigtime
*/

/*
    Board identifier
*/
#define BOARD_
#define BOARD_NAME                     "Bigtime"

/*
    Ethernet related stuff
*/
#define BOARD_PHY_ID                    0x00221560
#define BOARD_PHY_RMII

/*
    Board oscillators-related settings.
*/
#if !defined(STM32_LSECLK)
#define STM32_LSECLK                   32768U
#endif

#if !defined(STM32_HSECLK)
#define STM32_HSECLK                   26000000U
#endif

/*
    Board voltages
    Required for performance limits calculation.
*/
#define STM32_VDD                      330U

/*
    MCU type as defined in the ST header.
*/
#define STM32F407xx

/*
    IO pins assignments.
*/

#define GPIOA_PIN0                     0U
#define GPIOA_RMII_REF_CLK             1U
#define GPIOA_RMII_MDIO                2U
#define GPIOA_PIN3                     3U
#define GPIOA_PIN4                     4U
#define GPIOA_PIN5                     5U
#define GPIOA_PIN6                     6U
#define GPIOA_RMII_CRS_DV              7U
#define GPIOA_PIN8                     8U
#define GPIOA_USB_VBUS                 9U
#define GPIOA_PIN10                    10U
#define GPIOA_USB_DM                   11U
#define GPIOA_USB_DP                   12U
#define GPIOA_SWDIO                    13U
#define GPIOA_SWCLK                    14U
#define GPIOA_ROM_CS                   15U

#define GPIOB_PIN0                     0U
#define GPIOB_PIN1                     1U
#define GPIOB_PIN2                     2U
#define GPIOB_SHCP                     3U
#define GPIOB_STCP                     4U
#define GPIOB_DS                       5U
#define GPIOB_PIN6                     6U
#define GPIOB_PIN7                     7U
#define GPIOB_PIN8                     8U
#define GPIOB_PIN9                     9U
#define GPIOB_PIN10                    10U
#define GPIOB_RMII_TX_EN               11U
#define GPIOB_RMII_TXD0                12U
#define GPIOB_RMII_TXD1                13U
#define GPIOB_PIN14                    14U
#define GPIOB_PIN15                    15U

#define GPIOC_PIN0                     0U
#define GPIOC_RMII_MDC                 1U
#define GPIOC_PIN2                     2U
#define GPIOC_PIN3                     3U
#define GPIOC_RMII_RXD0                4U
#define GPIOC_RMII_RXD1                5U
#define GPIOC_PIN6                     6U
#define GPIOC_PIN7                     7U
#define GPIOC_PIN8                     8U
#define GPIOC_PIN9                     9U
#define GPIOC_ROM_SCK                  10U
#define GPIOC_ROM_MISO                 11U
#define GPIOC_ROM_MOSI                 12U
#define GPIOC_PIN13                    13U
#define GPIOC_PIN14                    14U
#define GPIOC_PIN15                    15U

#define GPIOD_PIN0                     0U
#define GPIOD_PIN1                     1U
#define GPIOD_PIN2                     2U
#define GPIOD_PIN3                     3U
#define GPIOD_PIN4                     4U
#define GPIOD_PIN5                     5U
#define GPIOD_PIN6                     6U
#define GPIOD_PIN7                     7U
#define GPIOD_PIN8                     8U
#define GPIOD_PIN9                     9U
#define GPIOD_PIN10                    10U
#define GPIOD_PIN11                    11U
#define GPIOD_PIN12                    12U
#define GPIOD_PIN13                    13U
#define GPIOD_PIN14                    14U
#define GPIOD_PIN15                    15U

#define GPIOE_PIN0                     0U
#define GPIOE_PIN1                     1U
#define GPIOE_PIN2                     2U
#define GPIOE_PIN3                     3U
#define GPIOE_PIN4                     4U
#define GPIOE_PIN5                     5U
#define GPIOE_PIN6                     6U
#define GPIOE_PIN7                     7U
#define GPIOE_PIN8                     8U
#define GPIOE_PIN9                     9U
#define GPIOE_PIN10                    10U
#define GPIOE_PIN11                    11U
#define GPIOE_PIN12                    12U
#define GPIOE_PIN13                    13U
#define GPIOE_PIN14                    14U
#define GPIOE_PIN15                    15U
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

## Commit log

2017-02-21 Did schematic, sketched board
    [bigtime.kicad_pcb, bigtime.sch]
2017-02-21 bump agg-kicad for npic6c596a
2017-02-21 Added limit resistors
    [bigtime.kicad_pcb, bigtime.sch]
2017-02-21 Rectangular board because life's too short
    [bigtime.kicad_pcb]
2017-02-21 Don't forget the mounting holes!
    [bigtime.kicad_pcb, bigtime.sch]
2017-03-01 added some ethernet bits
    [bigtime.sch]
2017-03-01 bump agg-kicad for kicad nightly fix
2017-03-01 Rescued and fixed library paths
    [bigtime.sch]
2017-03-01 separate sheet for ethernet
    [bigtime.sch, ethernet.sch]
2017-03-03 Roughed out ethernet sheet
    [bigtime.sch, ethernet.sch]
2017-03-05 Values for ethernet and max17503
    [ethernet.sch]
2017-03-06 STM32 support and 25EE MAC chip
    [bigtime.sch, ethernet.sch]
2017-03-24 test points, footprints, usb
    [bigtime.kicad_pcb, bigtime.sch, ethernet.sch]
2017-03-27 Specced part for brightness trimpot
    [bigtime.sch, ethernet.sch]
2017-03-28 New LDO, new dimmer network, zener
    [bigtime.sch, ethernet.sch]
2017-03-28 bump agg-kicad, position mechanical connectors
    [bigtime.kicad_pcb]
2017-03-28 Rough first go at placement minus some shrapnel
    [bigtime.kicad_pcb, bigtime.sch, ethernet.sch]
2017-03-29 nearly done first route
    [bigtime.kicad_pcb, bigtime.sch]
2017-03-29 Finished first (pretty awful) route
    [bigtime.kicad_pcb, bigtime.sch, ethernet.sch]
2017-03-30 Tidied SMPS layouts
    [bigtime.kicad_pcb]
2017-03-30 Made capacitors more consistent in vals+fps
    [bigtime.kicad_pcb, bigtime.sch, ethernet.sch]
2017-03-30 Fixed ERC with liberal application of pwr_flag
    [bigtime.sch, ethernet.sch]
2017-03-30 Tidied top half of board
    [bigtime.kicad_pcb, ethernet.sch]
2017-03-30 Beefed 12V and V_LED_BUS
    [bigtime.kicad_pcb]
2017-03-31 Finished cleaning routing, rounded corners
    [bigtime.kicad_pcb, bigtime.sch]
2017-03-31 Final finishing touches and gerbers
    [bigtime-B.Cu.gbl, bigtime-B.Mask.gbs, bigtime-B.SilkS.gbo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]
2017-03-31 more silk fiddling
    [bigtime-B.Cu.gbl, bigtime-B.Mask.gbs, bigtime-B.SilkS.gbo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]
2017-03-31 Reduce mask clearance, budge connectors up
    [bigtime-B.Cu.gbl, bigtime-B.Mask.gbs, bigtime-B.SilkS.gbo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]
2017-03-31 Removed MAC from silk
    [bigtime-B.Cu.gbl, bigtime-B.Mask.gbs, bigtime-B.SilkS.gbo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]
2017-03-31 rename edge cuts for dirtypcbs
    [bigtime-Edge.Cuts.gbr]
2017-03-31 Order codes for capacitor shrapnel
    [bigtime.sch, ethernet.sch]
2017-03-31 specced remaining parts
    [bigtime.sch, ethernet.sch]
2017-04-02 Firmware initial commit: it builds!
    [bigtime.sch, ethernet.sch]
2017-04-03 Add seconds+milliseconds display options
2017-04-07 Display driver in progress
2017-04-22 Simple threade ntpserv for tester
2017-04-22 thread attribute instead of subclassing
2017-04-22 daemonise ntp thread
2017-04-25 prototyped tester usb-ser interface
2017-05-05 Remove tests from f/w so it fits in 128k
    Some sort of bug means I can only program the first 128k sector of flash using
    the BMP programmer. As a workaround removing various bits makes the firmware
    small enough to fit. Thanks Adam for this.
    [main.c]
2017-05-22 Add make power/unpower
2017-05-22 Removed seconds & DP sep, display test
    Display test code all works now. Also fixed digit ordering issues. Removed
    seconds because it was complicating things and I'm never going to make a 6
    digit version. Removed DP separator because I now have the separate colon board
    [display.c, main.c]
2017-05-22 Fix buffering issue with usb shell
    Responses from USB Shell were being buffered and not sent until a few hundred
    characters were received. Replacing jon's dongle usb configuration with the
    stock ChibiOS configuration from
    ChibiOS/demos/STM32/RT-STM32F407-OLIMEX_E407-LWIP-FATFS-USB/usbcfg.? fixed the
    problem.
    [main.c]
2017-05-23 Load config on boot, no longer force DHCP enable
    [main.c]
2017-05-24 New display thread with sync indicator
2017-05-24 Add adam's hard-fault stack trace magic thing

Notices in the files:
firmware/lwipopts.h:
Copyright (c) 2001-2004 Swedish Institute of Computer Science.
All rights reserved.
